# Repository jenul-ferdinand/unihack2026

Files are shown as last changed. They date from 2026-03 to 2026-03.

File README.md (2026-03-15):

# Antrum MK 1

## Inspiration

Antrum was inspired by a simple goal: helping protect people in high-risk underground environments before a rescue ever becomes necessary. We wanted to support cave explorers and miners who can become disoriented, separated, or trapped in places where visibility is low, communication is limited, and every wrong turn increases danger. The story of the Thai youth soccer team trapped in a cave for an extended period was a major point of inspiration for us. Their rescue was extraordinary, but it also showed how devastating it can be when people lose their bearings in an environment that is difficult to navigate and even harder to search. With Antrum, we wanted to build something preventative: a device that helps users keep track of their partner’s location in the cave and switch to a mode that guides them back toward the cave entrance from the point where recording began.

## What it does

1. Pair both devices before going into cave.
2. Strap it on to your leg, then go caving.
3. If you get lost, use the LED indicators to find where your caving partner is.
4. If you want to know the way back to the start, switch modes.
5. Once you surface; exploration data is sent to the cloud, then you can visualise both your paths on the webapp (Altrum DASH).

## How we built it

Our team was able to move quickly because we had a strong mix of complementary skills. Chris led the hardware coding and embedded implementation in C, Jenul focused on full-stack development and maintainable software architecture, Maria brought expertise in electrical engineering, PCB design, and 3D printing, and Manan contributed a strong mathematical foundation that helped shape the positioning logic behind the device. That combination allowed us to work in parallel, make decisions quickly, and connect hardware, software, and modelling into one system.

On the hardware side, we rapidly researched the components we needed and designed the device around an ESP32 as the embedded master controller. We used the XC4508 for 2.4 GHz radio communication between paired devices, and the ICM20948 as the IMU to capture movement data for cavers and miners. To estimate position, we built our tracking approach around dead reckoning and ZUPT (Davis, 1607/1880; Foxlin, 2005), but the maths went further than simple integration. We used zero-velocity updates (ZUPT; Foxlin, 2005) to detect when a device was effectively stationary by checking whether the gyroscope magnitude satisfied $\|\omega\| < \omega_{\text{zupt}}$ and whether acceleration stayed close to gravity using $\left|\|a\| - g\right| < \epsilon_a$. When those conditions held, we set velocity to zero, held position at the last trusted point, and prevented stationary drift from accumulating.

$$
\|\omega\| < \omega_{\text{zupt}}, \qquad \left|\|a\| - g\right| < \epsilon_a \;\Longrightarrow\; v = 0
$$

We also added big-movement gating and small-movement rejection so that only believable motion was integrated, while small jitter and noise were damped out before they could corrupt the trajectory. To make partner tracking meaningful, each device shared its position, yaw, initial yaw, and timestamp over the RF24 link, allowing us to compute a shared yaw offset $\Delta \psi = \psi_{\text{peer},0} - \psi_{\text{local},0}$, rotate coordinates into a common frame, and then evaluate relative position as $p_{\text{rel}} = p_{\text{peer}} - p_{\text{local}}$.

$$
\Delta \psi = \psi_{\text{peer},0} - \psi_{\text{local},0}, \qquad p_{\text{rel}} = p_{\text{peer}} - p_{\text{local}}
$$

On the software side, we built the web application early using mocked data so frontend progress would not be blocked by hardware bring-up. We kept everything in a monorepo so the whole team could collaborate efficiently, used TypeScript and Hono for a fast backend, and chose Angular for a clean and maintainable frontend architecture. To reduce deployment friction during the hackathon, we set up CI/CD early, deployed the backend to a Google Cloud virtual machine, and hosted the frontend on Vercel.

## Challenges we ran into

One of our biggest challenges was the physical build process itself. We ran into difficulties with 3D printing the casing and ultimately had to rely on a 24/7 same-day printing business in Tarneit, which meant making a roughly one-hour round trip just to collect the enclosures for our two handheld devices. We also spent significant time working through gyroscope and IMU alignment issues so that the motion data would be usable for tracking. On top of that, sourcing parts was difficult early in the hackathon, and we had to travel across multiple electronics stores on the first day just to gather the components needed to get the prototype built.

## Accomplishments that we're proud of

We are especially proud of how well our team used each person’s strengths to move the project forward. By combining hardware, software, mathematics, electronics, and design skills effectively, we were able to build a working system rather than just an isolated prototype. We are also proud that we successfully integrated embedded hardware, a web platform, and a 3D-printed casing into one cohesive product. Just as importantly, every member of the team pushed themselves, contributed at a high level, and learned new skills along the way.

## What we learned

One of our biggest technical lessons was how much real-world constraints change your ideal design. Chris learned that the RF24 module behaved very differently from other radios he had used before, especially because it could not transmit and receive simultaneously. That limitation forced us to redesign communication around a master-slave packet exchange instead of a simpler synchronisation model. Maria learned not only the value of structuring CAD work with separate part files in SolidWorks so enclosure designs stay editable, but also how much product design is a balance between the ideal form, the physical limitations of PLA printing, and the time constraints of the project itself. Jenul learned a great deal from the hardware-software integration process, especially around cleaning, compressing, and transforming noisy IMU output into data that could be rendered meaningfully in the frontend, drawing on practical mathematical techniques for filtering, approximation, and more efficient representation. Manon learned how quickly neat theoretical models break down in physical environments, and how important it is to adapt mathematical methods to interference, sensor drift, and imperfect real-world conditions.

As a team, we learned how powerful strong cross-functional collaboration can be under tight time pressure. This project only worked because hardware, firmware, mathematics, CAD, and web development were constantly informing each other. Chris and Jenul aligned embedded output with the web platform, Maria coordinated hardware and enclosure design, and Manon helped translate complex mathematical ideas into something the software could actually use. None of us started with deep knowledge of every part of the system, but by working closely and teaching each other as we went, we were able to build a much more complete and functional product than any one discipline could have produced alone.

## What's next for Antrum MK 1

For a Mark 2 version of Antrum, we want to develop a fully waterproof casing so the device can reliably support underwater cave divers as well. That next iteration would also replace our current 2.4 GHz RF approach with UWB, since standard RF communication at that frequency is not suitable underwater. We are confident the core idea can extend to that environment, but the hackathon timeframe was too short for us to redesign the communications layer and properly engineer, test, and validate an underwater-ready version in this iteration.

## References

### Knowledgebase

#### Dead reckoning method
- Davis, J. (1607/1880). The seaman’s secrets. In A. H. Markham (Ed.), *The voyages and works of John Davis, the navigator* (pp. 230–337). Hakluyt Society. https://www.spirasolaris.ca/sbb9d1.pdf

#### ZUPT (Zero-Velocity Update method for IMUs)
- Foxlin, E. (2005). Pedestrian tracking with shoe-mounted inertial sensors. *IEEE Computer Graphics and Applications, 25*(6), 38–46.

### Video references

- Good Morning America. (2023, September 14). Mark Dickey speaks out about rescue from Turkish cave l GMA [Video]. YouTube. https://www.youtube.com/watch?v=CsPicsmCib0

- 7NEWS. (2025, December 1). Cave rescue expert called for diver recovery [Video]. YouTube. https://www.youtube.com/watch?v=ekqP49hA5rI

- TODAY. (2023, November 29). Rescued Thai cave survivor shares update 5 years later [Video]. YouTube. https://www.youtube.com/watch?v=HQukKjfrN18

- NBC News. (2018, December 7). Flashback: How the Chilean miners rescue happened | NBC Nightly News [Video]. YouTube. https://www.youtube.com/watch?v=jDxf6MT-LaM

### Documentation

- Angular. (n.d.). Angular Documentation. Retrieved March 14, 2026, from https://angular.dev/overview

- Microsoft. (n.d.). The TypeScript handbook. Retrieved March 14, 2026, from https://www.typescriptlang.org/docs/handbook/intro.html

- Hono. (n.d.). Hono documentation. Retrieved March 14, 2026, from https://hono.dev/docs/

- Anthropic. (n.d.). Common workflows. In Claude Code Docs. Retrieved March 14, 2026, from https://docs.anthropic.com/en/docs/claude-code/common-workflows

- PlatformIO. (n.d.). PlatformIO documentation. Retrieved March 14, 2026, from https://docs.platformio.org/en/latest/

- Dassault Systèmes. (n.d.). SOLIDWORKS Web Help. Retrieved March 14, 2026, from https://help.solidworks.com/

### Third-party software used

- SolidWorks
- Claude Code
- ChatGPT Codex
- Adobe Photoshop
- Capcut
- VS Code

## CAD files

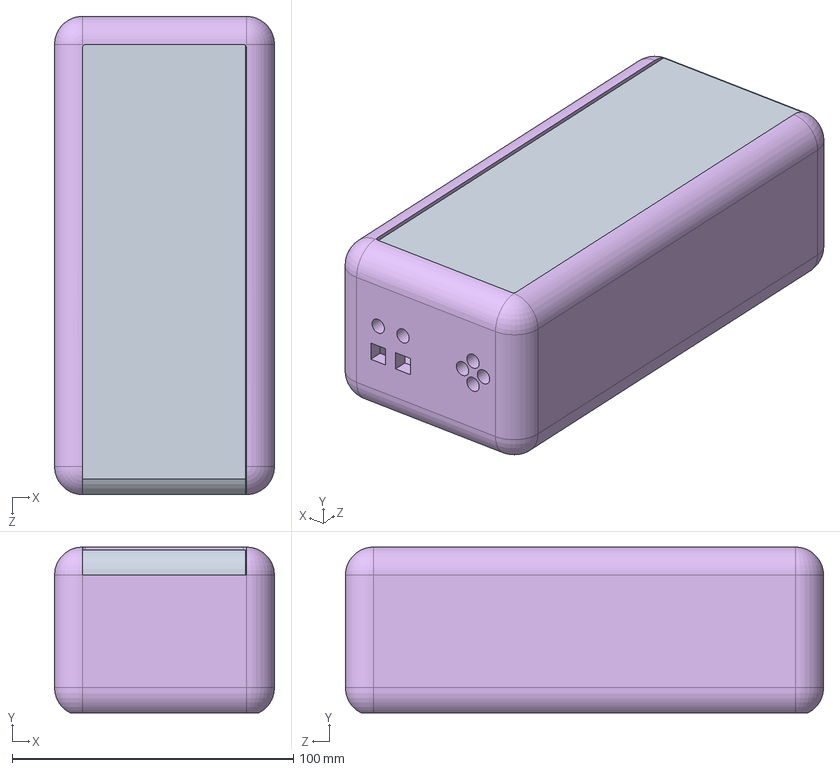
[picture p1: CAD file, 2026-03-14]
solidworks/main_assembly.SLDASM
78.2 x 59.0 x 170.0 mm
HandheldCasing
battery
esp32_model
icm20948
radio
lid

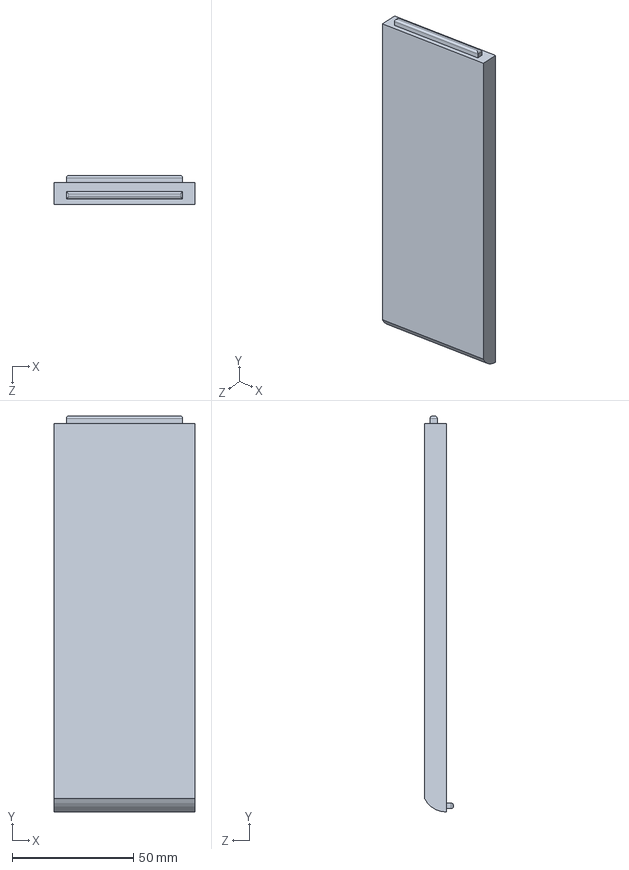
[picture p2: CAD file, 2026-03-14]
solidworks/lid.SLDPRT
57.9 x 163.0 x 12.0 mm

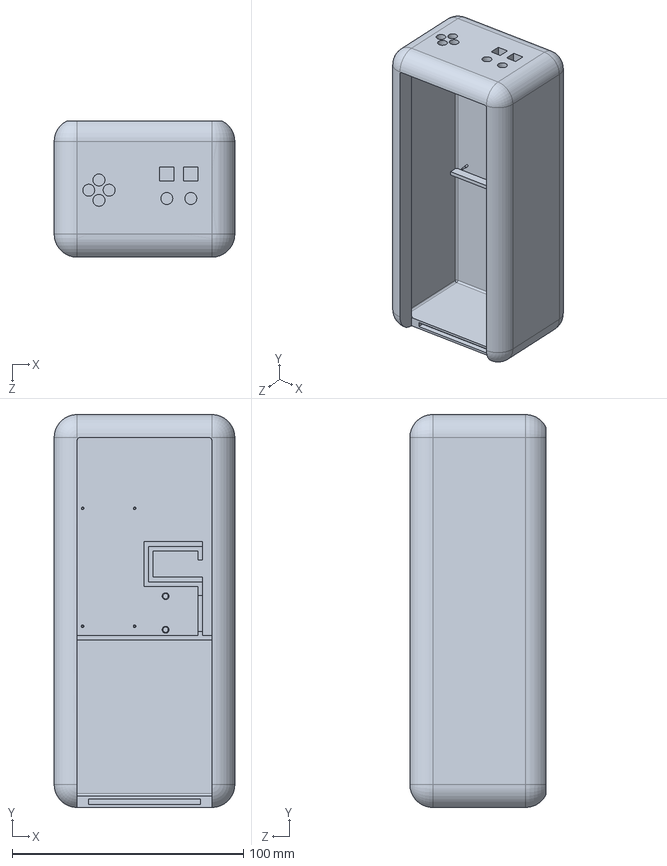
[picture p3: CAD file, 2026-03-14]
solidworks/HandheldCasing.SLDPRT
78.2 x 170.0 x 59.0 mm

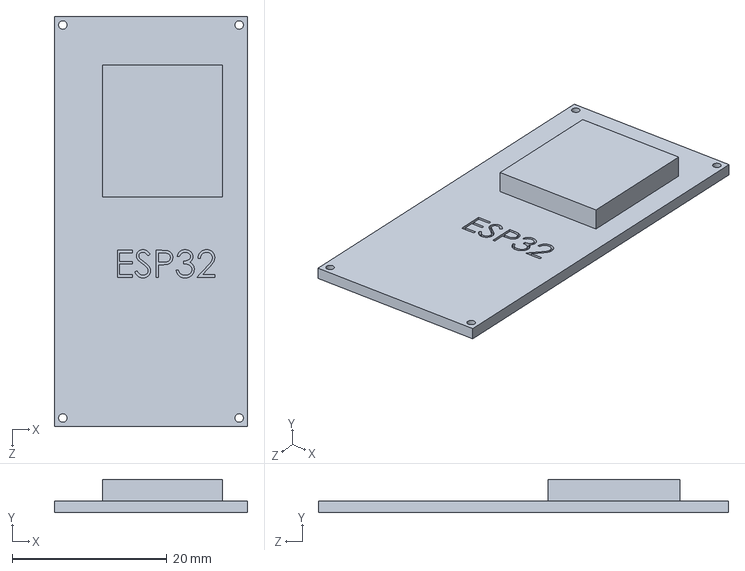
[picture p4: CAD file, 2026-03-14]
solidworks/esp32_model.SLDPRT
25.0 x 4.30 x 53.0 mm

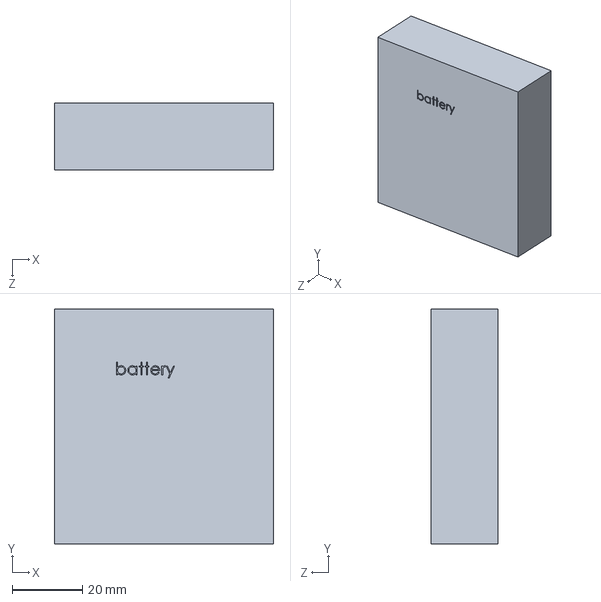
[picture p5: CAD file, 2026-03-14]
solidworks/battery.SLDPRT
62.5 x 67.0 x 19.0 mm

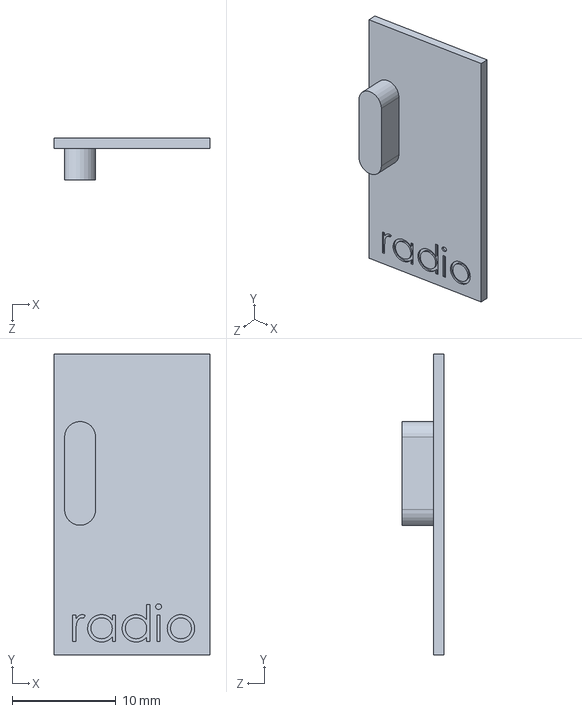
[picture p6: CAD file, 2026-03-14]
solidworks/radio.SLDPRT
15.0 x 29.0 x 4.00 mm

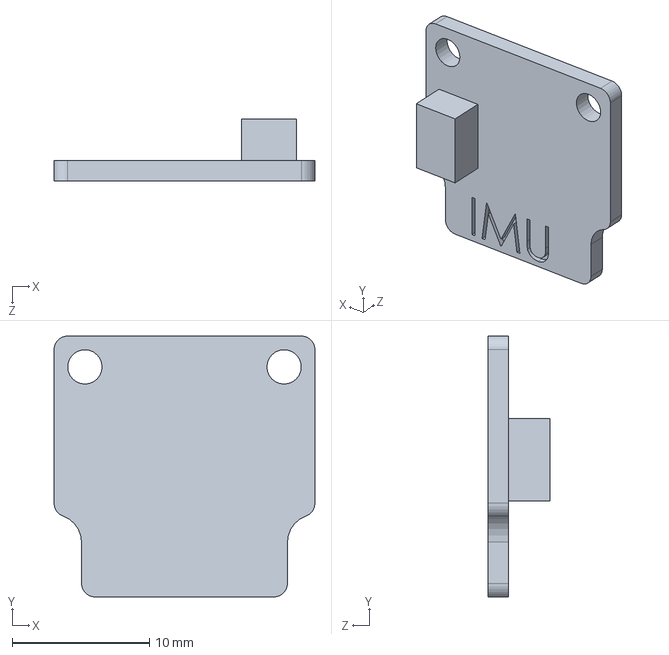
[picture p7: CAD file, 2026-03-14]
solidworks/icm20948.SLDPRT
19.0 x 19.0 x 4.50 mm

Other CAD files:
solidworks/HandheldCasing.STL
solidworks/lid.STL

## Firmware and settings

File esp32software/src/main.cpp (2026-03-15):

#include <Arduino.h>
#include <HTTPClient.h>
#include <SPI.h>
#include <SPIFFS.h>
#include <WiFi.h>
#include <RF24.h>
#include <math.h>
#include <memory>

#include "imu.h"
#include "link.h"
#include "time_sync.h"
#include "imu_accel.h"
#include "dead_reckoning.h"
#include "debug_config.h"

/*
 * Main firmware sketch for the handheld ESP32 node.
 *
 * Runtime flow:
 * 1. Read and fuse IMU data.
 * 2. Detect stationary / ZUPT conditions and clamp drift while still.
 * 3. Update dead-reckoned position and heading.
 * 4. Exchange state with the peer device over nRF24.
 * 5. Derive relative direction to the peer and optionally correct local drift.
 * 6. Persist telemetry locally and upload it in batches when WiFi is available.
 *
 * Device role is compile-time configurable:
 * - time master / poller: drives radio exchanges and defines the shared frame.
 * - time slave / responder: answers polls, locks to the master's clock, and
 *   aligns its local frame to the master's initial yaw.
 */

#define CE_PIN 4
#define CSN_PIN 5
static constexpr uint8_t LEFT_LED_PIN = 33;
static constexpr uint8_t RIGHT_LED_PIN = 25;
static constexpr uint8_t BACK_LED_PIN = 26;
static constexpr uint8_t FRONT_LED_PIN = 27;
static constexpr uint8_t DIRECTION_LED_PINS[] = {
    LEFT_LED_PIN,
    RIGHT_LED_PIN,
    BACK_LED_PIN,
    FRONT_LED_PIN,
};

// CHANGE THESE PER DEVICE
#define SELF_ID 2
#define IS_TIME_MASTER 0

#if IS_TIME_MASTER
#define IS_POLLER 1
#else
#define IS_POLLER 0
#endif

RF24 radio(CE_PIN, CSN_PIN);

static uint16_t gSeq = 0;
static StatePacket localPkt = {};
static StatePacket peerPkt = {};
static TimeSyncState gTimeSync;
static bool gHavePeerPacket = false;
static bool gPeerPacketStale = false;
static unsigned long gLastPeerPacketMs = 0;

// ---------- Tunable thresholds ----------
static const float G_MS2 = 9.80665f;
static const float STATIONARY_GYRO_DPS = 2.0f;
static const float STATIONARY_ACC_ERR_MS2 = 0.35f;
static const float ZUPT_GYRO_DPS = 1.2f;
static const float ZUPT_ACC_ERR_MS2 = 0.20f;
static const float MAX_PITCH_STEP_DEG = 10.0f;

static const int STILL_SAMPLES_TO_LATCH = 8;
static const int MOVE_SAMPLES_TO_RELEASE = 4;

// Hard reset after being still a bit
static const unsigned long STILL_RESET_MS = 1200;

// Shared-frame alignment
static bool gInitialYawLocked = false;
static float gInitialYawDeg = 0.0f;
static bool gSharedFrameLocked = false;
static float gSharedYawOffsetDeg = 0.0f;

// ---------- Local estimator/debug state ----------
/*
 * Scratch state owned by the sketch layer.
 *
 * The IMU module exposes raw and fused measurements, but the sketch needs an
 * additional layer of state to apply stationary clamping, remember the boot
 * origin, and store debug-friendly values that are later serialized to the
 * radio packet and telemetry log.
 */
struct MotionState
{
    // Raw sensor/debug
    float rawAx = 0, rawAy = 0, rawAz = 0;
    float rawGx = 0, rawGy = 0, rawGz = 0;
    float rawMx = 0, rawMy = 0, rawMz = 0;

    float linAxB = 0, linAyB = 0, linAzB = 0;
    float linAxW = 0, linAyW = 0, linAzW = 0;

    // Raw pose from IMU layer, shifted so startup = origin
    float rawPosX = 0, rawPosY = 0, rawPosZ = 0;
    float rawVelX = 0, rawVelY = 0, rawVelZ = 0;

    // Clamped pose
    float clampPosX = 0, clampPosY = 0, clampPosZ = 0;
    float clampVelX = 0, clampVelY = 0, clampVelZ = 0;

    // Persistent correction offset:
    // corrected = raw + correction
    float corrX = 0, corrY = 0, corrZ = 0;

    // Startup origin from IMU layer
    float originX = 0, originY = 0, originZ = 0;
    bool originSet = false;

    bool stationary = false;
    bool zupt = false;

    float gyroNorm = 0;
    float accNorm = 0;
    float accErr = 0;

    int stillCount = 0;
    int moveCount = 0;

    bool imuHoldActive = false;
    unsigned long stillSinceMs = 0;
    bool resetDoneThisStillness = false;
    bool prevHold;

    float rawRoll = 0, rawPitch = 0, rawYaw = 0;
    float clampRoll = 0, clampPitch = 0, clampYaw = 0;
    float corrRoll = 0, corrPitch = 0, corrYaw = 0;
    float acceptedRawPitch = 0;
    bool acceptedRawPitchValid = false;

    float orientOffRoll = 0, orientOffPitch = 0, orientOffYaw = 0;

    float holdRollRef = 0, holdPitchRef = 0, holdYawRef = 0;
    bool angleHoldRefValid;

    bool holdLatched = false;
};

static MotionState gMotion;

static DeadReckoningState gDeadReckoning;
static DeadReckoningPeerView gDeadPeerView;

// ---------- Timing ----------
static unsigned long gLastDebugMs = 0;
static unsigned long gLastTelemetryLogMs = 0;
static unsigned long gLastWifiCheckMs = 0;
static constexpr unsigned long PEER_PACKET_STALE_MS = 500;

// ---------- Telemetry persistence / upload ----------
static constexpr const char *WIFI_SSID = "Christopher's A35";
static constexpr const char *WIFI_PASSWORD = "its a secret";
static constexpr const char *COMMS_BASE_URL = "http://136.112.170.87:3000";
static constexpr const char *COMMS_START_URL = "http://136.112.170.87:3000/api/comms/start";
static constexpr const char *COMMS_PACKET_URL = "http://136.112.170.87:3000/api/comms";
static constexpr const char *COMMS_STOP_URL = "http://136.112.170.87:3000/api/comms/stop";
static constexpr const char *TELEMETRY_LOG_PATH = "/telemetry.bin";
static constexpr const char *TELEMETRY_TMP_PATH = "/telemetry.tmp";
static constexpr unsigned long TELEMETRY_LOG_INTERVAL_MS = 100;
static constexpr unsigned long WIFI_CHECK_INTERVAL_MS = 10000;
static constexpr unsigned long WIFI_CONNECT_TIMEOUT_MS = 5000;
static constexpr size_t TELEMETRY_MAX_FILE_BYTES = 7 * 1024 * 1024;
static constexpr size_t TELEMETRY_TRIM_TARGET_BYTES = 5 * 1024 * 1024;

struct __attribute__((packed)) TelemetryVec3
{
    float x;
    float y;
    float z;
};

struct __attribute__((packed)) TelemetryLogRecord
{
    // Local wall-clock in milliseconds when the sample was written to SPIFFS.
    uint32_t loggedAtMs;

    // Shared-frame status so backend traces can be interpreted correctly.
    uint8_t initialYawLocked;
    float initialYawDeg;
    uint8_t sharedFrameLocked;
    float sharedYawOffsetDeg;

    // Local motion estimate before and after clamp correction.
    TelemetryVec3 rawPos;
    TelemetryVec3 rawVel;
    TelemetryVec3 corrOffset;
    TelemetryVec3 clampedPos;
    TelemetryVec3 clampedVel;

    // Last peer packet that informed the relative-direction estimate.
    uint8_t peerId;
    uint32_t peerTimeUs;
    TelemetryVec3 peerPos;
    float peerYawDeg;
    float peerInitYawDeg;
    float peerSpeedMps;

    // Final relative position/bearing view derived from both devices.
    TelemetryVec3 deltaXyz;
    float distanceM;
    float bearingWorldDeg;
    float bearingLocalDeg;
};

static_assert(sizeof(TelemetryLogRecord) == 127, "TelemetryLogRecord layout changed unexpectedly");

static bool gTelemetryPausedForSend = false;

// ---------- Utility ----------
static float wrapAngleDeg(float deg)
{
    while (deg > 180.0f)
        deg -= 360.0f;
    while (deg < -180.0f)
        deg += 360.0f;
    return deg;
}

static void setDirectionLeds(uint8_t directionCode)
{
    const bool showDirection = gHavePeerPacket && !gPeerPacketStale;

    digitalWrite(LEFT_LED_PIN, LOW);
    digitalWrite(RIGHT_LED_PIN, LOW);
    digitalWrite(BACK_LED_PIN, LOW);
    digitalWrite(FRONT_LED_PIN, LOW);

    if (!showDirection)
        return;

    switch (directionCode)
    {
        case LINK_PEER_LEFT:
            digitalWrite(LEFT_LED_PIN, HIGH);
            break;
        case LINK_PEER_RIGHT:
            digitalWrite(RIGHT_LED_PIN, HIGH);
            break;
        case LINK_PEER_BACK:
            digitalWrite(BACK_LED_PIN, HIGH);
            break;
        case LINK_PEER_FORWARD:
            digitalWrite(FRONT_LED_PIN, HIGH);
            break;
        default:
            break;
    }
}

static float vecNorm3(float x, float y, float z)
{
    return sqrtf(x * x + y * y + z * z);
}

static float degToRad(float deg)
{
    return deg * PI / 180.0f;
}

static bool wifiConfigured()
{
    return WIFI_SSID[0] != '\0' && COMMS_BASE_URL[0] != '\0';
}

static void appendFloat(String &json, float value, int decimals)
{
    char buffer[32];
    snprintf(buffer, sizeof(buffer), "%.*f", decimals, value);
    json += buffer;
}

static void appendVec3Json(String &json, const char *key, const TelemetryVec3 &vec, int decimals)
{
    json += "\"";
    json += key;
    json += "\":{";
    json += "\"x\":";
    appendFloat(json, vec.x, decimals);
    json += ",\"y\":";
    appendFloat(json, vec.y, decimals);
    json += ",\"z\":";
    appendFloat(json, vec.z, decimals);
    json += "}";
}

static TelemetryVec3 makeVec3(float x, float y, float z)
{
    TelemetryVec3 vec{};
    vec.x = x;
    vec.y = y;
    vec.z = z;
    return vec;
}

static TelemetryLogRecord captureTelemetryRecord()
{
    // Capture a self-contained snapshot so logging remains independent from
    // later in-loop updates.
    TelemetryLogRecord record{};
    record.loggedAtMs = millis();

    record.initialYawLocked = gInitialYawLocked ? 1 : 0;
    record.initialYawDeg = gInitialYawDeg;
    record.sharedFrameLocked = gSharedFrameLocked ? 1 : 0;
    record.sharedYawOffsetDeg = gSharedYawOffsetDeg;

    record.rawPos = makeVec3(gMotion.rawPosX, gMotion.rawPosY, gMotion.rawPosZ);
    record.rawVel = makeVec3(gMotion.rawVelX, gMotion.rawVelY, gMotion.rawVelZ);
    record.corrOffset = makeVec3(gMotion.corrX, gMotion.corrY, gMotion.corrZ);
    record.clampedPos = makeVec3(gMotion.clampPosX, gMotion.clampPosY, gMotion.clampPosZ);
    record.clampedVel = makeVec3(gMotion.clampVelX, gMotion.clampVelY, gMotion.clampVelZ);

    record.peerId = peerPkt.deviceId;
    record.peerTimeUs = peerPkt.timeUs;
    record.peerPos = makeVec3(peerPkt.posX, peerPkt.posY, peerPkt.posZ);
    record.peerYawDeg = peerPkt.yawDeg;
    record.peerInitYawDeg = peerPkt.initYawDeg;
    record.peerSpeedMps = peerPkt.speedMps;

    record.deltaXyz = makeVec3(gDeadPeerView.dx, gDeadPeerView.dy, gDeadPeerView.dz);
    record.distanceM = gDeadPeerView.distance;
    record.bearingWorldDeg = gDeadPeerView.bearingWorldDeg;
    record.bearingLocalDeg = gDeadPeerView.bearingLocalDeg;

    return record;
}

static String telemetryRecordToJson(const TelemetryLogRecord &record)
{
    // Build JSON manually to keep heap usage predictable on-device.
    String json;
    json.reserve(700);

    json += "{";
    json += "\"shared_frame\":{";
    json += "\"initial_yaw_locked\":";
    json += String(record.initialYawLocked);
    json += ",\"initial_yaw_deg\":";
    appendFloat(json, record.initialYawDeg, 2);
    json += ",\"shared_frame_locked\":";
    json += String(record.sharedFrameLocked);
    json += ",\"shared_yaw_offset_deg\":";
    appendFloat(json, record.sharedYawOffsetDeg, 2);
    json += "},";

    json += "\"position_velocity\":{";
    appendVec3Json(json, "raw_pos", record.rawPos, 3);
    json += ",";
    appendVec3Json(json, "raw_vel", record.rawVel, 3);
    json += ",";
    appendVec3Json(json, "corr_offset", record.corrOffset, 3);
    json += ",";
    appendVec3Json(json, "clamped_pos", record.clampedPos, 3);
    json += ",";
    appendVec3Json(json, "clamped_vel", record.clampedVel, 3);
    json += "},";

    json += "\"peer_state\":{";
    json += "\"peer_id\":";
    json += String(record.peerId);
    json += ",\"peer_t_us\":";
    json += String(record.peerTimeUs);
    json += ",";
    appendVec3Json(json, "peer_pos", record.peerPos, 3);
    json += ",\"peer_yaw_deg\":";
    appendFloat(json, record.peerYawDeg, 2);
    json += ",\"peer_init_yaw_deg\":";
    appendFloat(json, record.peerInitYawDeg, 2);
    json += ",\"peer_speed_mps\":";
    appendFloat(json, record.peerSpeedMps, 3);
    json += "},";

    json += "\"relative_to_peer\":{";
    appendVec3Json(json, "delta_xyz", record.deltaXyz, 3);
    json += ",\"distance_m\":";
    appendFloat(json, record.distanceM, 3);
    json += ",\"bearing_world_deg\":";
    appendFloat(json, record.bearingWorldDeg, 2);
    json += ",\"bearing_local_deg\":";
    appendFloat(json, record.bearingLocalDeg, 2);
    json += "}";
    json += "}";

    return json;
}

static void trimTelemetryLogIfNeeded()
{
    // Keep the log bounded by rewriting only the most recent tail of the file.
    File src = SPIFFS.open(TELEMETRY_LOG_PATH, FILE_READ);
    if (!src)
        return;

    const size_t currentSize = src.size();
    if (currentSize <= TELEMETRY_MAX_FILE_BYTES)
    {
        src.close();
        return;
    }

    const size_t bytesToKeep = min(currentSize, TELEMETRY_TRIM_TARGET_BYTES);
    const size_t startOffset = currentSize - bytesToKeep;
    src.seek(startOffset, SeekSet);

    File dst = SPIFFS.open(TELEMETRY_TMP_PATH, FILE_WRITE);
    if (!dst)
    {
        src.close();
        return;
    }

    uint8_t buffer[512];
    while (src.available())
    {
        const size_t chunk = src.read(buffer, sizeof(buffer));
        if (chunk == 0)
            break;
        dst.write(buffer, chunk);
    }

    src.close();
    dst.close();

    SPIFFS.remove(TELEMETRY_LOG_PATH);
    SPIFFS.rename(TELEMETRY_TMP_PATH, TELEMETRY_LOG_PATH);
}

static void appendTelemetryLogRecord(const TelemetryLogRecord &record)
{
    File file = SPIFFS.open(TELEMETRY_LOG_PATH, FILE_APPEND);
    if (!file)
        return;

    file.write(reinterpret_cast<const uint8_t *>(&record), sizeof(record));
    file.close();
    trimTelemetryLogIfNeeded();
}

static void discardTelemetryPrefix(size_t bytesToDrop)
{
    // Drop records that were acknowledged by the backend while preserving any
    // unsent tail in the same file.
    File src = SPIFFS.open(TELEMETRY_LOG_PATH, FILE_READ);
    if (!src)
        return;

    const size_t totalSize = src.size();
    if (bytesToDrop >= totalSize)
    {
        src.close();
        SPIFFS.remove(TELEMETRY_LOG_PATH);
        return;
    }

    src.seek(bytesToDrop, SeekSet);

    File dst = SPIFFS.open(TELEMETRY_TMP_PATH, FILE_WRITE);
    if (!dst)
    {
        src.close();
        return;
    }

    uint8_t buffer[512];
    while (src.available())
    {
        const size_t chunk = src.read(buffer, sizeof(buffer));
        if (chunk == 0)
            break;
        dst.write(buffer, chunk);
    }

    src.close();
    dst.close();

    SPIFFS.remove(TELEMETRY_LOG_PATH);
    SPIFFS.rename(TELEMETRY_TMP_PATH, TELEMETRY_LOG_PATH);
}

static bool ensureWifiConnected()
{
    if (!wifiConfigured())
    {
        Serial.println("WiFi check skipped: SSID or webhook URL not configured.");
        return false;
    }

    if (WiFi.status() == WL_CONNECTED)
    {
        Serial.print("WiFi already connected. IP=");
        Serial.println(WiFi.localIP());
        return true;
    }

    Serial.print("Attempting WiFi connection to SSID: ");
    Serial.println(WIFI_SSID);
    Serial.print("WiFi status before begin: ");
    Serial.println(WiFi.status());
    WiFi.mode(WIFI_STA);
    WiFi.begin(WIFI_SSID, WIFI_PASSWORD);

    const unsigned long startMs = millis();
    while (WiFi.status() != WL_CONNECTED && (millis() - startMs) < WIFI_CONNECT_TIMEOUT_MS)
    {
        Serial.print("WiFi connecting, status=");
        Serial.println(WiFi.status());
        delay(100);
    }

    Serial.print("WiFi connect result status=");
    Serial.println(WiFi.status());
    if (WiFi.status() == WL_CONNECTED)
    {
        Serial.print("WiFi connected. IP=");
        Serial.println(WiFi.localIP());
    }

    return WiFi.status() == WL_CONNECTED;
}

static bool hasQueuedTelemetry()
{
    File file = SPIFFS.open(TELEMETRY_LOG_PATH, FILE_READ);
    if (!file)
        return false;

    const bool hasData = file.size() >= sizeof(TelemetryLogRecord);
    file.close();
    return hasData;
}

static void printQueuedTelemetryStats()
{
    File file = SPIFFS.open(TELEMETRY_LOG_PATH, FILE_READ);
    if (!file)
    {
        Serial.println("Queued telemetry: file missing or empty.");
        return;
    }

    const size_t bytes = file.size();
    const size_t samples = bytes / sizeof(TelemetryLogRecord);
    file.close();

    Serial.print("Queued telemetry bytes=");
    Serial.print(bytes);
    Serial.print(", samples=");
    Serial.println(samples);
}

static bool postJson(const char *url, const String &payload, const char *label)
{
    if (!wifiConfigured() || !ensureWifiConnected())
        return false;

    HTTPClient http;
    Serial.print(label);
    Serial.print(" POST to ");
    Serial.println(url);
    Serial.print(label);
    Serial.print(" payload bytes=");
    Serial.println(payload.length());

    http.begin(url);
    http.addHeader("Content-Type", "application/json");
    http.addHeader("Accept", "application/json");
    http.useHTTP10(true);

    std::unique_ptr<char[]> requestBody(new char[payload.length() + 1]);
    memcpy(requestBody.get(), payload.c_str(), payload.length() + 1);

    const int responseCode = http.POST(reinterpret_cast<uint8_t *>(requestBody.get()), payload.length());
    const String responseBody = http.getString();
    http.end();

    Serial.print(label);
    Serial.print(" response code=");
    Serial.println(responseCode);
    Serial.print(label);
    Serial.print(" response body=");
    Serial.println(responseBody);

    return responseCode >= 200 && responseCode < 300;
}

static bool postTelemetryStart()
{
    return postJson(COMMS_START_URL, "{\"start\":1}", "Telemetry start");
}

static bool postTelemetryStop()
{
    return postJson(COMMS_STOP_URL, "{\"stop\":1}", "Telemetry stop");
}

static bool postTelemetryRecord(const TelemetryLogRecord &record)
{
    String payload;
    payload.reserve(800);
    payload += "{";
    payload += "\"device_id\":";
    payload += String(SELF_ID);
    payload += ",\"sample\":";
    payload += telemetryRecordToJson(record);
    payload += "}";
    return postJson(COMMS_PACKET_URL, payload, "Telemetry packet");
}

static bool flushQueuedTelemetry(size_t &sentRecordsOut)
{
    sentRecordsOut = 0;

    if (!wifiConfigured() || !ensureWifiConnected())
        return false;

    File file = SPIFFS.open(TELEMETRY_LOG_PATH, FILE_READ);
    if (!file)
        return false;

    const size_t availableRecords = file.size() / sizeof(TelemetryLogRecord);
    if (availableRecords == 0)
    {
        file.close();
        return true;
    }

    if (!postTelemetryStart())
    {
        file.close();
        return false;
    }

    TelemetryLogRecord record{};
    size_t sentRecords = 0;
    while (file.read(reinterpret_cast<uint8_t *>(&record), sizeof(record)) == sizeof(record))
    {
        if (!postTelemetryRecord(record))
            break;
        sentRecords++;
    }

    file.close();

    if (sentRecords > 0)
        discardTelemetryPrefix(sentRecords * sizeof(TelemetryLogRecord));

    if (sentRecords != availableRecords)
        return false;

    if (!postTelemetryStop())
        return false;

    sentRecordsOut = sentRecords;
    return true;
}

static void maybeLogTelemetry()
{
    // Logging pauses while a send batch is in-flight so the upload code can
    // reason about a stable file prefix.
    if (gTelemetryPausedForSend)
        return;

    const unsigned long nowMs = millis();
    if (nowMs - gLastTelemetryLogMs < TELEMETRY_LOG_INTERVAL_MS)
        return;

    gLastTelemetryLogMs = nowMs;
    const TelemetryLogRecord record = captureTelemetryRecord();
    appendTelemetryLogRecord(record);
}
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
void loop()
{
    // The loop is intentionally staged: sense -> classify -> estimate ->
    // exchange with peer -> maintain diagnostics/telemetry.
    imu_update();
    captureImuState();
    detectMotionFlags();
    updateStationaryHold();
    applyClamps();

    DeadReckoningInput drInput{};
    drInput.linAccelBodyX = gMotion.linAxB;
    drInput.linAccelBodyY = gMotion.linAyB;
    drInput.linAccelBodyZ = gMotion.linAzB;
    drInput.gyroHeadingDeg = gMotion.clampYaw;
    drInput.comparePitchDeg = gMotion.rawPitch;
    drInput.stationary = gMotion.stationary;
    drInput.zupt = gMotion.zupt;
    deadReckoningUpdate(gDeadReckoning, drInput, micros());
    if (gMotion.stationary || gMotion.zupt)
        deadReckoningAnchorPosition(gDeadReckoning, gMotion.clampPosX, gMotion.clampPosY, 0.0f);
    maybeLockInitialYaw();

    fillLocalPacket(localPkt);
    linkSetLocalState(localPkt);

#if IS_POLLER
    if (linkExchange(radio, peerPkt))
    {
        gHavePeerPacket = true;
        gPeerPacketStale = false;
        gLastPeerPacketMs = millis();
        computeRelativeDirection();
    }
#else
    if (linkPollResponder(radio, peerPkt))
    {
        const uint32_t localRxUs = micros();
        gHavePeerPacket = true;
        gPeerPacketStale = false;
        gLastPeerPacketMs = millis();

        if (peerPkt.deviceId == 1)
            timeSyncObserveMaster(gTimeSync, localRxUs, peerPkt.timeUs);

        maybeLockSharedFrameFromPeer();
        computeRelativeDirection();
    }
#endif

    if (gHavePeerPacket && (millis() - gLastPeerPacketMs > PEER_PACKET_STALE_MS))
    {
        gPeerPacketStale = true;
        computeRelativeDirection();
    }

    setDirectionLeds(gDeadPeerView.directionCode);

#if IS_POLLER
    // Master always defines the shared frame
    if (gInitialYawLocked && !gSharedFrameLocked)
    {
        gSharedYawOffsetDeg = 0.0f;
        gSharedFrameLocked = true;
    }
#endif

    if (millis() - gLastDebugMs >= 1000)
    {
        gLastDebugMs = millis();
        printDebug();
    }

    maybeLogTelemetry();
    maybeUploadTelemetry();

#if IS_POLLER
    delay(20);
#else
    delay(2);
#endif
}

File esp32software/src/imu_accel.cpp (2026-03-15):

#include "imu_accel.h"
#include "imu_math.h"
#include <Arduino.h>
#include <math.h>
#include "quarternian.h"

/*
 * This file intentionally implements a conservative translational estimator.
 *
 * Consumer-grade IMU double integration drifts quickly, so the code only
 * integrates when acceleration/gyro thresholds indicate a clear motion burst,
 * damps velocity hard when motion becomes ambiguous, and clamps the resulting
 * position to a small radius around the origin.
 */

static constexpr float G_MSS = 9.80665f;
static constexpr float ACC_DEADBAND_MSS = 0.25f;

// Very aggressive gating
static constexpr float BURST_ACC_THRESH_MSS = 1.20f;
static constexpr float BURST_GYRO_THRESH_DPS = 12.0f;
static constexpr float EXIT_BURST_ACC_THRESH_MSS = 0.35f;
static constexpr float EXIT_BURST_GYRO_THRESH_DPS = 3.0f;

// Very small speeds are treated as accumulated integration noise.
static constexpr float MIN_VALID_SPEED_MPS = 0.01f;
static constexpr float MAX_VALID_SPEED_MPS = 100.0f;

void imuAccelInit(ImuAccelCal &cal, ImuMotionState &motion)
{
    cal.gyroBiasDps[0] = cal.gyroBiasDps[1] = cal.gyroBiasDps[2] = 0.0f;
    cal.accelBiasMss[0] = cal.accelBiasMss[1] = cal.accelBiasMss[2] = 0.0f;

    for (int i = 0; i < 3; ++i)
    {
        motion.linBody[i] = 0.0f;
        motion.linWorld[i] = 0.0f;
        motion.velWorld[i] = 0.0f;
        motion.posWorld[i] = 0.0f;
    }

    motion.motionBurst = false;
    motion.travelMeters = 0.0f;
    motion.pendingMeters = 0.0f;
}

void imuAccelCalibrateStill(ImuAccelCal &cal,
                            float sumGx, float sumGy, float sumGz,
                            float sumAx, float sumAy, float sumAz,
                            int samples)
{
    if (samples <= 0)
        return;

    cal.gyroBiasDps[0] = sumGx / samples;
    cal.gyroBiasDps[1] = sumGy / samples;
    cal.gyroBiasDps[2] = sumGz / samples;

    cal.accelBiasMss[0] = sumAx / samples;
    cal.accelBiasMss[1] = sumAy / samples;
    cal.accelBiasMss[2] = (sumAz / samples) - G_MSS;
}

void imuAccelProcess(ImuMotionState &motion,
                     const float quat[4],
                     float rawAx, float rawAy, float rawAz,
                     float rawGx, float rawGy, float rawGz,
                     float dt,
                     bool stationaryHold)
{
    // 1. Remove gravity in the body frame and rotate into the world frame.
    float gravityBody[3];
    imuMathComputeGravityBodyFromQuat(quat, gravityBody);

    motion.linBody[0] = rawAx - gravityBody[0];
    motion.linBody[1] = rawAy - gravityBody[1];
    motion.linBody[2] = rawAz - gravityBody[2];
    imuMathApplyDeadband(motion.linBody, ACC_DEADBAND_MSS);

    motion.linWorld[0] = motion.linBody[0];
    motion.linWorld[1] = motion.linBody[1];
    motion.linWorld[2] = motion.linBody[2];
    imuMathRotateVectorByQuat(quat, motion.linBody, motion.linWorld);
    imuMathApplyDeadband(motion.linWorld, ACC_DEADBAND_MSS);

    // Euler values are debug-only here.
    float rollDeg = 0.0f;
    float pitchDeg = 0.0f;
    float yawDeg = 0.0f;
    imuMathQuatToEulerDeg(quat, rollDeg, pitchDeg, yawDeg);
    rollDeg *= 4; // Cater for imu resistance

    // Clamp small gyro values to zero before using them in the burst detector.
    const float gyroRaw[3] = {rawGx, rawGy, rawGz};
    float gyroClamped[3] = {rawGx, rawGy, rawGz};

    if (fabsf(gyroClamped[0]) < GYRO_NOISE_THRESH_DPS)
        gyroClamped[0] = 0.0f;
    if (fabsf(gyroClamped[1]) < GYRO_NOISE_THRESH_DPS)
        gyroClamped[1] = 0.0f;
    if (fabsf(gyroClamped[2]) < GYRO_NOISE_THRESH_DPS)
        gyroClamped[2] = 0.0f;

    const float linAccNorm = imuMathNorm3(
        motion.linBody[0], motion.linBody[1], motion.linBody[2]);

    const float gyroNormRaw = imuMathNorm3(
        gyroRaw[0], gyroRaw[1], gyroRaw[2]);

    const float gyroNormClamped = imuMathNorm3(
        gyroClamped[0], gyroClamped[1], gyroClamped[2]);

    float reportRoll = rollDeg;
    float reportPitch = pitchDeg;
    float reportYaw = yawDeg;
/*
    if (gMotion.holdLatched)
    {
        reportRoll = gMotion.holdRollRef;
        reportPitch = gMotion.holdPitchRef;
        reportYaw = gMotion.holdYawRef;
    }
    */

#if IMU_DEBUG
    Serial.println();
    Serial.println("====== IMU ACCEL DEBUG ======");
    Serial.print("dt: ");
    Serial.println(dt, 6);

    Serial.print("linBody: (");
    Serial.print(motion.linBody[0], 4);
    Serial.print(", ");
    Serial.print(motion.linBody[1], 4);
    Serial.print(", ");
    Serial.print(motion.linBody[2], 4);
    Serial.println(")");

    Serial.print("linWorld: (");
    Serial.print(motion.linWorld[0], 4);
    Serial.print(", ");
    Serial.print(motion.linWorld[1], 4);
    Serial.print(", ");
    Serial.print(motion.linWorld[2], 4);
    Serial.println(")");

    Serial.print("linAccNorm: ");
    Serial.println(linAccNorm, 4);

    Serial.print("velWorld BEFORE: (");
    Serial.print(motion.velWorld[0], 4);
    Serial.print(", ");
    Serial.print(motion.velWorld[1], 4);
    Serial.print(", ");
    Serial.print(motion.velWorld[2], 4);
    Serial.println(")");
#endif

#if GYRO_DEBUG
    Serial.println("------ GYRO DEBUG ------");
    Serial.print("gyro raw dps: (");
    Serial.print(gyroRaw[0], 4);
    Serial.print(", ");
    Serial.print(gyroRaw[1], 4);
    Serial.print(", ");
    Serial.print(gyroRaw[2], 4);
    Serial.println(")");

    Serial.print("gyro clamped dps: (");
    Serial.print(gyroClamped[0], 4);
    Serial.print(", ");
    Serial.print(gyroClamped[1], 4);
    Serial.print(", ");
    Serial.print(gyroClamped[2], 4);
    Serial.println(")");

    Serial.print("gyroNorm raw: ");
    Serial.println(gyroNormRaw, 4);

    Serial.print("gyroNorm clamped: ");
    Serial.println(gyroNormClamped, 4);

    Serial.print("gyro noise threshold dps: ");
    Serial.println(GYRO_NOISE_THRESH_DPS, 4);

    Serial.print("roll deg: ");
    Serial.println(rollDeg, 3);

    Serial.print("pitch deg: ");
    Serial.println(pitchDeg, 3);

    Serial.print("yaw deg: ");
    Serial.println(yawDeg, 3);
/*
    Serial.println("Final clamp:");
    Serial.print("roll deg: ");
    Serial.println(reportRoll, 3);

    Serial.print("pitch deg: ");
    Serial.println(reportPitch, 3);

    Serial.print("yaw deg: ");
    Serial.println(reportYaw, 3);

    */
#endif

    // 2. Decide whether the current frame belongs to a "real movement burst".
    if (!motion.motionBurst)
    {
        if (linAccNorm > BURST_ACC_THRESH_MSS || gyroNormClamped > BURST_GYRO_THRESH_DPS)
            motion.motionBurst = true;
    }
    else
    {
        if (linAccNorm < EXIT_BURST_ACC_THRESH_MSS && gyroNormClamped < EXIT_BURST_GYRO_THRESH_DPS)
            motion.motionBurst = false;
    }
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

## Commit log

2026-03-13 3d: initial body shape
    [HandheldCasing.SLDPRT]
2026-03-13 added chamfer
    added a 0.5mm chamfer to the bottom fillet edge so that it prints properly
    [HandheldCasing.SLDPRT]
2026-03-13 Embedded: imu test
2026-03-14 3d: created model of esp32
    [esp32_model.SLDPRT]
2026-03-14 embedded: split up imu code
2026-03-14 3d: created IMU model
    [icm20948.SLDPRT]
2026-03-14 3d: updated component models
    [HandheldCasing.SLDPRT, battery.SLDPRT, esp32_model.SLDPRT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]
2026-03-14 embedded: Added drift reduction for stationary holds
    [imu_accel.cpp, main.cpp]
2026-03-14 maths: add script to generate sample imu data
2026-03-14 embedded: Added gyro debug info
2026-03-14 3d: added slots for PCBs
    [HandheldCasing.SLDPRT, battery.SLDPRT, esp32_model.SLDPRT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]
2026-03-14 3d: fixed wrong dimensions for slots
    [HandheldCasing.SLDPRT]
2026-03-14 3d: updated slot dimensions
    [HandheldCasing.SLDPRT]
2026-03-14 frontend: demo button in info panel
2026-03-14 3d: added holes for buttons and LEDs
    [HandheldCasing.SLDPRT, esp32_model.SLDPRT, main_assembly.SLDASM]
2026-03-14 completed main body design
    [HandheldCasing.SLDPRT, main_assembly.SLDASM]
2026-03-14 3d: added holders for lid
    [HandheldCasing.SLDPRT]
2026-03-14 3d: added fillets so that it prints nicely
    [HandheldCasing.SLDPRT]
2026-03-14 3d: updated lid slot dimensions
    [HandheldCasing.SLDPRT]
2026-03-14 embedded: Fixed rotation drift
    [imu.cpp, imu_accel.cpp, main.cpp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]
2026-03-14 3d: created lid
    [lid.SLDPRT]
2026-03-14 3d: added lid to model
    [main_assembly.SLDASM]
2026-03-14 3d: exported files
    [HandheldCasing.3mf, HandheldCasing.STL, lid.SLDPRT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]
2026-03-14 3d: updated tolerance on lid
    [lid.SLDPRT]
2026-03-14 3d: deleted unnecessary print files
    [HandheldCasing.3mf]
2026-03-14 embedded: added webserver posting in json from the esp32
2026-03-14 frontend: delete button and run info
2026-03-15 embedded: fixed rotation issues
    [dead_reckoning.h, imu.cpp, imu_accel.cpp]
